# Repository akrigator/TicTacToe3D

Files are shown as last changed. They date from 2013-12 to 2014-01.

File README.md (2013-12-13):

TicTacToe3D
===========

Проект реализует игру в трехмерные крестики-нолики при помощи Arduino UNO.

После запуска игроки делают ходы друг за другом, пока игровое поле не будет заполнено или места не будет достаточно для кона. По завершению игры строится списки построенных линий каждым игроком. С задержкой 1-2 секунды отображаются по одной линии каждого игрока. Таким образом наглядно демонстрируются все линии и возможное превосходство победителя: если начали отображатся линии одного цвета, то игрок этого цвета победил.

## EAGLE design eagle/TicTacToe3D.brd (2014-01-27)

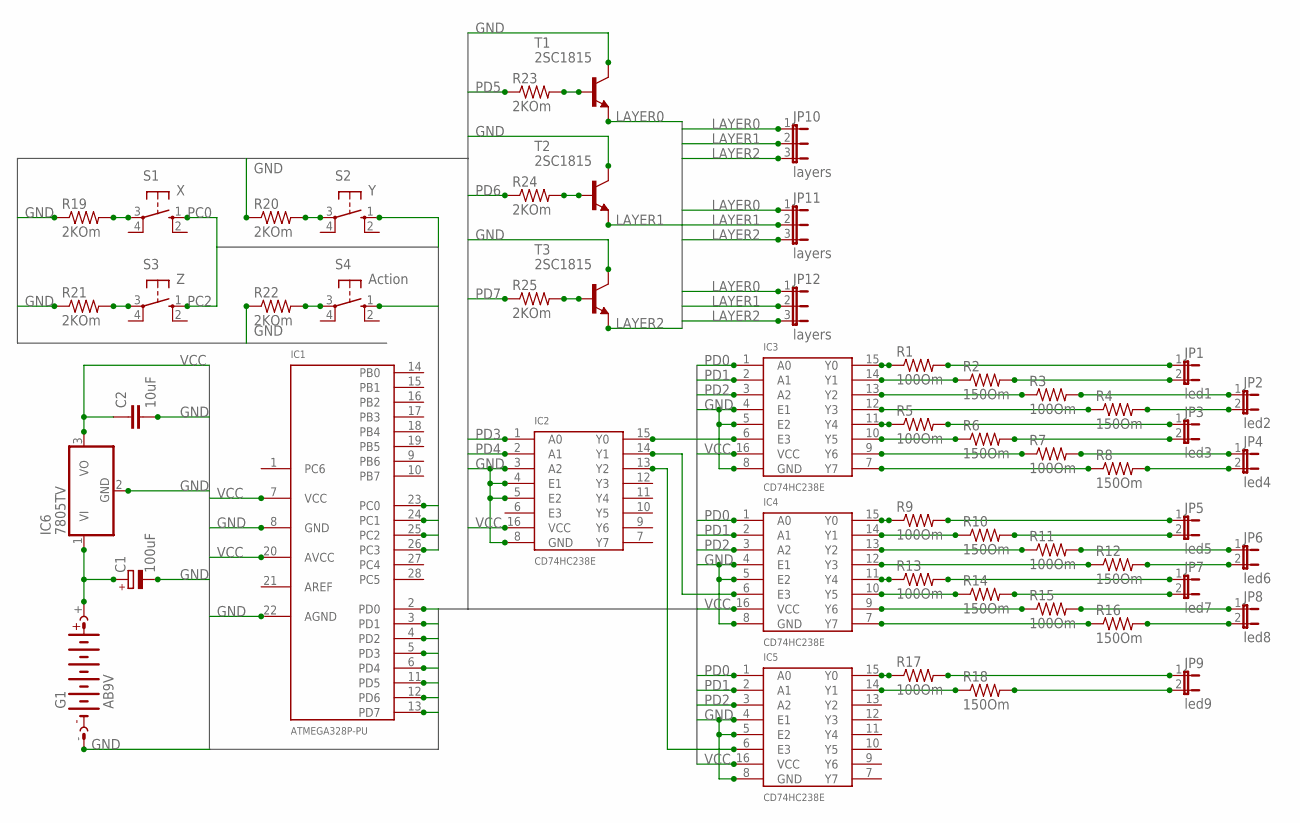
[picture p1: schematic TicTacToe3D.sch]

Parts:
C1: 100uF; E2-4
C2: 10uF; C050-024X044
G1: AB9V
IC1: ATMEGA328P-PU; 28P3
IC2, IC3, IC4, IC5: CD74HC238E; 16PDIP
IC6: 7805TV; TO220V
JP1: led1; JP1
JP2: led2; JP1
JP3: led3; JP1
JP4: led4; JP1
JP5: led5; JP1
JP6: led6; JP1
JP7: led7; JP1
JP8: led8; JP1
JP9: led9; JP1
JP10, JP11, JP12: layers; JP2
R1, R3, R5, R7, R9, R11, R13, R15, R17: 100Om; 0204/7
R2, R4, R6, R8, R10, R12, R14, R16, R18: 150Om; 0204/7
R19, R20, R21, R22, R23, R24, R25: 2KOm; 0204/7
S1: X; B3F-10XX
S2: Y; B3F-10XX
S3: Z; B3F-10XX
S4: Action; B3F-10XX
T1, T2, T3: 2SC1815; TO92-ECB

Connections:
GND: C1.-, C2.2, G1.-, IC1.8 (GND), IC1.22 (AGND), IC2.3 (A2), IC2.4 (E1), IC2.5 (E2), IC2.8 (GND), IC3.4 (E1), IC3.5 (E2), IC3.8 (GND), IC4.4 (E1), IC4.5 (E2), IC4.8 (GND), IC5.4 (E1), IC5.5 (E2), IC5.8 (GND), IC6.2 (GND), R19.1, R20.1, R21.1, R22.1, T1.C, T2.C, T3.C
LAYER0: JP10.1, JP11.1, JP12.1, T1.E
LAYER1: JP10.2, JP11.2, JP12.2, T2.E
LAYER2: JP10.3, JP11.3, JP12.3, T3.E
unnamed: C1.+, G1.+, IC6.1 (VI)
unnamed: IC2.15 (Y0), IC3.6 (E3)
unnamed: IC2.14 (Y1), IC4.6 (E3)
unnamed: IC2.13 (Y2), IC5.6 (E3)
unnamed: IC3.15 (Y0), R1.1
unnamed: IC3.14 (Y1), R2.1
unnamed: IC3.12 (Y3), R4.1
unnamed: IC3.13 (Y2), R3.1
unnamed: IC5.14 (Y1), R18.1
unnamed: R19.2, S1.3
unnamed: R20.2, S2.3
unnamed: R21.2, S3.3
unnamed: IC3.11 (Y4), R5.1
unnamed: IC3.10 (Y5), R6.1
unnamed: IC3.9 (Y6), R7.1
unnamed: IC3.7 (Y7), R8.1
unnamed: R22.2, S4.3
unnamed: R24.2, T2.B
unnamed: R25.2, T3.B
unnamed: R23.2, T1.B
unnamed: JP1.2, R2.2
unnamed: JP2.2, R4.2
unnamed: JP3.2, R6.2
unnamed: JP4.2, R8.2
unnamed: JP5.2, R10.2
unnamed: JP6.2, R12.2
unnamed: JP7.2, R14.2
unnamed: JP8.2, R16.2
unnamed: IC4.15 (Y0), R9.1
unnamed: IC4.14 (Y1), R10.1
unnamed: IC4.13 (Y2), R11.1
unnamed: IC4.12 (Y3), R12.1
unnamed: IC4.11 (Y4), R13.1
unnamed: IC4.10 (Y5), R14.1
unnamed: IC4.9 (Y6), R15.1
unnamed: IC4.7 (Y7), R16.1
unnamed: IC5.15 (Y0), R17.1
unnamed: JP9.2, R18.2
unnamed: JP1.1, R1.2
unnamed: JP2.1, R3.2
unnamed: JP3.1, R5.2
unnamed: JP4.1, R7.2
unnamed: JP5.1, R9.2
unnamed: JP6.1, R11.2
unnamed: JP7.1, R13.2
unnamed: JP8.1, R15.2
unnamed: JP9.1, R17.2
PC0: IC1.23 (PC0), S1.1 (S)
PC1: IC1.24 (PC1), S2.1 (S)
PC2: IC1.25 (PC2), S3.1 (S)
PC3: IC1.26 (PC3), S4.1 (S)
PD0: IC1.2 (PD0), IC3.1 (A0), IC4.1 (A0), IC5.1 (A0)
PD1: IC1.3 (PD1), IC3.2 (A1), IC4.2 (A1), IC5.2 (A1)
PD2: IC1.4 (PD2), IC3.3 (A2), IC4.3 (A2), IC5.3 (A2)
PD3: IC1.5 (PD3), IC2.1 (A0)
PD4: IC1.6 (PD4), IC2.2 (A1)
PD5: IC1.11 (PD5), R23.1
PD6: IC1.12 (PD6), R24.1
PD7: IC1.13 (PD7), R25.1
VCC: C2.1, IC1.7 (VCC), IC1.20 (AVCC), IC2.16 (VCC), IC3.16 (VCC), IC4.16 (VCC), IC5.16 (VCC), IC6.3 (VO)

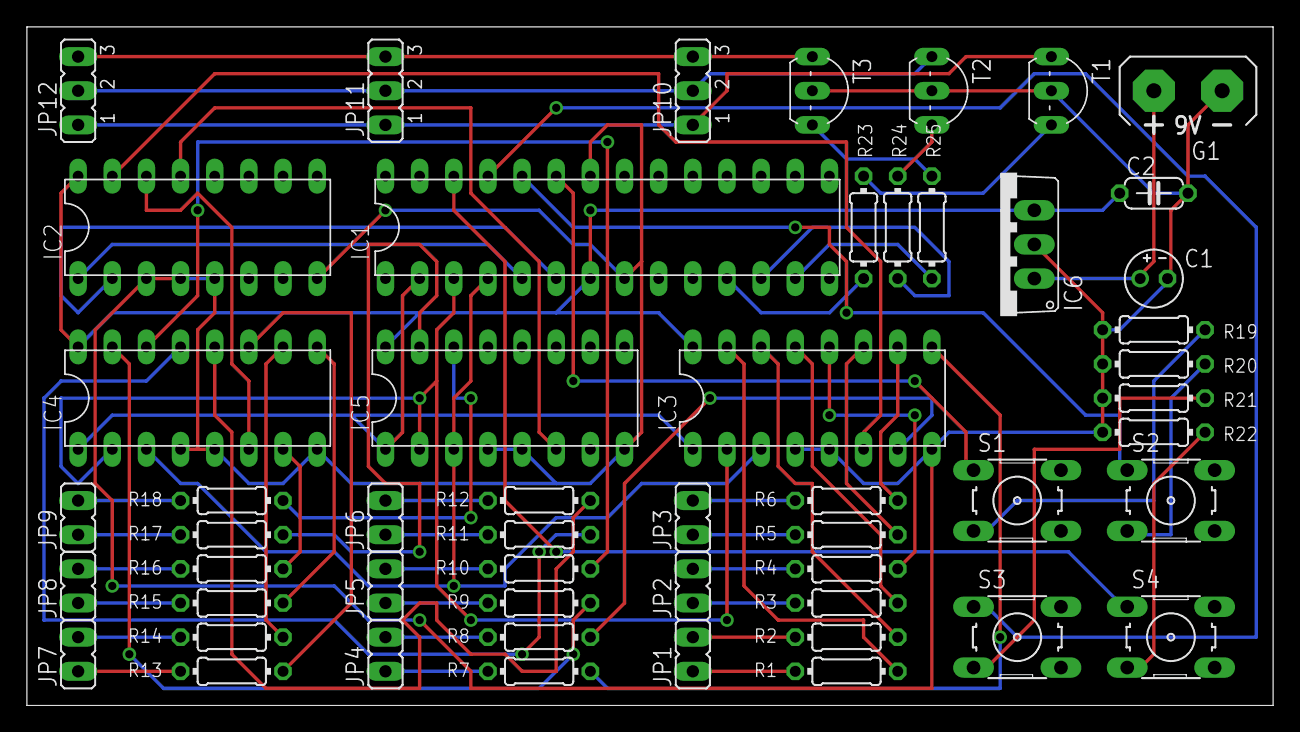
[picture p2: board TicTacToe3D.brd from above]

Board: 2 copper layers, 92.7 x 50.5 mm, 53 parts (0 on the bottom side), 64 nets.

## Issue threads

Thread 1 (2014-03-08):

Replace all buttons to the analog port A0

akrigator, 2014-03-08:
http://nnm.me/blogs/e-troll/arduino-podklyuchenie-neskolkih-knopok-k-odnomu-analogovomu-vhodu/

akrigator, 2015-03-12:
The IR controle will be used at the new revision of board, so the enhancement will not be emplemented.

Closed 2015-03-12.

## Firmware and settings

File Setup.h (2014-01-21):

#ifndef _SETUP_H_
#define _SETUP_H_

#define X_SIZE						3
#define Y_SIZE						3
#define Z_SIZE						3
#define CUBE_SIZE					X_SIZE * Y_SIZE * Z_SIZE
#define STRAIGHT_LENGTH				X_SIZE

#define PLAYERS_COUNT				2	

#define COLORS_PER_LED				2
enum Color { BLUE = 0, RED };
#define BRIGHTNESS					500	// Time interval (microseconds) in which ONLY an one led is light
#define MANIPULATOR_BLINK_INTERVAL	500
#define ANIMATE_INTERVAL			3000

#define DEBONCE_INTERVAL			20	// Time interval (milliseconds) of the buttons debonce
#define BUTTONS_COUNT				4
#define X_ITERATOR_PIN				A5
#define Y_ITERATOR_PIN				A2
#define Z_ITERATOR_PIN				A4
#define ACTION_PIN					A3

#define DECODER_BITS				5	// log2 (X_SIZE * Y_SIZE * COLORS_PER_LED)
#define D0							2
#define D1							3
#define D2							4
#define D3							5
#define D4							6

#define CATHODE_PINS				Z_SIZE
#define C0							7
#define C1							8
#define C2							9

#endif

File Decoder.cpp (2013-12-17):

#include "Decoder.h"
#include "Setup.h"
#include "Arduino.h"

Decoder::Decoder(uint8_t colorsPerLed, uint8_t xSize, uint8_t decoderPinsCount, uint8_t* decoderPins, uint8_t cathodePinsCount, uint8_t* cathodePins) {
	_colorsPerLed = colorsPerLed;
	_xSize = xSize;
	_decoderPinsCount = decoderPinsCount;
	_cathodePinsCount = cathodePinsCount;

	_decoderPins = new uint8_t[_decoderPinsCount];
	for (uint8_t pin = 0; pin < _decoderPinsCount; pin++) {
		_decoderPins[pin] = decoderPins[pin];
	}

	_cathodePins = new uint8_t[_cathodePinsCount];
	for (uint8_t pin = 0; pin < _cathodePinsCount; pin++) {
		_cathodePins[pin] = cathodePins[pin];
	}

	for (int pin = 0; pin < _decoderPinsCount; pin++) {
		pinMode(_decoderPins[pin], OUTPUT);
	}
	for (int pin = 0; pin < _cathodePinsCount; pin++) {
		pinMode(_cathodePins[pin], OUTPUT);
	}
}

Decoder::~Decoder() {
	delete[] _decoderPins;
	delete[] _cathodePins;
}

void Decoder::cathode(uint8_t layer) {
	for (int pin = 0; pin < _cathodePinsCount; pin++) {
		if (pin == layer || layer >= _cathodePinsCount) {
			digitalWrite(_cathodePins[pin], HIGH);
		}
		else {
			digitalWrite(_cathodePins[pin], LOW);
		}
	}
}

void Decoder::cathodesOff() {
	for (int pin = 0; pin < _cathodePinsCount; pin++) {
		digitalWrite(_cathodePins[pin], LOW);
	}
}

void Decoder::displayNum(int brightness, uint8_t ledNum) {
	ledNum = constrain(ledNum, 0, CUBE_SIZE);
	for (int weight = 1, pin = 0; pin < _decoderPinsCount; weight = weight << 1, pin++)
		digitalWrite(_decoderPins[pin], (ledNum & weight) >> pin);
	delayMicroseconds(brightness);
	cathodesOff();
}

void Decoder::display(int brightness, uint8_t color, uint8_t x, uint8_t y, uint8_t z) {
	int lednum = y * _xSize + x;
	cathode(z);
	displayNum(brightness, _colorsPerLed * lednum + color);
}

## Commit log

2013-12-17 Supply of the decoder power pin is removed
    LEDs turn off via cathode's supply interruption instead of anode.
2014-01-21 Replace buttons + fixing issue of the rules
    The rule with 7 straight step is fixed.
    [Setup.h]
2014-01-27 Add eagle project
    [TicTacToe3D.brd, TicTacToe3D.sch]
